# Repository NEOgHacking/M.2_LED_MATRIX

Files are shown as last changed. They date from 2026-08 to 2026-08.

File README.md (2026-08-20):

# M.2 LED Matrix
render

## Description
This is an M.2 compatible LED Matrix board to add an matrix to your desktop PC as a small little display. You can play cool GIFs on this matrix and can control it completely from your PC. This was a speed run done during Kai his ysws speed run. It is made to be as cheep as possible while still being and up to spec M.2 card and uses a 4 layer PCB in the standard 2242 M.2 size. It uses the PCIE protocol to talk to the PC and the PC will be able to send the commands straight to the RP2354 via UART. The RP2354 controls the 11x10 LED matrix and is crammed in on the backside of the PCB.

## Motivation & Idea
I started this project when i was brainstorming in a huddle with allot of people while thinking of ideas for Kai his ysws speedrun. I wanted to create something that would push me a bit and let me learn a bit more about some things but still be doable in 2 days. After some thinking i came up with the beautiful idea to add and LED matrix onto a M.2 card. It would be controlled by a simple microcontroller and it would have a way to interface with the PC it sits in via a protocol over M.2. I settled on the PCIE protocol after a bit of research because it was the one i could get chips for to convert it to UART easily and cheaply, that was one of the other things. This whole project needed to be within budget and that budget isn't big, at $50 it was something to work with. After some researching i found out that the RP2354 was a really cheap microcontroller i could use so i went with that one, also because i know it pretty well.

## Specs
M.2 2242 size
RP2354A microcontroller
CH382L conversion chip
107 LEDs 11x10 matrix
PCIE protocol

## Schematic






## PCB





## BOM

|Reference |Qty|Value |DNP|Exclude from BOM|Exclude from Board|Exclude from Simulation|Exclude from Position Files|Footprint |Datasheet |LCSC |
|---|---|---|---|---|---|---|---|---|---|---|
|C1 |1  |100u | | | | |${EXCLUDE_FROM_POS_FILES}  |Capacitor_Tantalum_SMD:CP_EIA-3528-21_Kemet-B | |C7196 |
|C2,C3 |2  |34p | | | | |${EXCLUDE_FROM_POS_FILES}  |Capacitor_SMD:C_0402_1005Metric | |C70465 |
|C4,C14,C15 |3  |10u | | | | |${EXCLUDE_FROM_POS_FILES}  |Custom:C_Polarized_0805_2012Metric | |C1969735 |
|C5,C6,C7,C9,C10,C11,C12,C13,C16,C26,C28,C29,C30,C31,C32,C33,C34,C36 |18 |100n | | | | |${EXCLUDE_FROM_POS_FILES}  |Capacitor_SMD:C_0402_1005Metric | |C1525 |
|C17,C18,C19,C20 |4  |1u | | | | |${EXCLUDE_FROM_POS_FILES}  |Capacitor_SMD:C_0402_1005Metric | |C29266 |
|C21,C22 |2  |4u7 | | | | |${EXCLUDE_FROM_POS_FILES}  |Custom:C_0402_1005Metric_small_pads | |C23733 |
|C23,C24 |2  |15p | | | | |${EXCLUDE_FROM_POS_FILES}  |Capacitor_SMD:C_0402_1005Metric | |C1548 |
|C25,C27 |2  |4u7 | | | | |${EXCLUDE_FROM_POS_FILES}  |Capacitor_SMD:C_0402_1005Metric | |C23733 |
|D1,D2,D3,D4,D8,D9,D10,D11,D12,D13,D14,D15,D16,D17,D18,D19,D20,D21,D22,D23,D24,D25,D26,D27,D28,D29,D30,D31,D32,D33,D34,D35,D36,D37,D38,D39,D40,D41,D42,D43,D44,D45,D46,D47,D48,D49,D50,D51,D52,D53,D54,D55,D56,D57,D58,D59,D60,D61,D62,D63,D64,D65,D66,D67,D68,D69,D70,D71,D72,D73,D74,D75,D76,D77,D78,D79,D80,D81,D82,D83,D84,D85,D86,D87,D88,D89,D90,D91,D92,D93,D94,D95,D96,D97,D98,D99,D100,D101,D102,D103,D104,D105,D106,D107,D108,D109,D110|107|LED | | | | |${EXCLUDE_FROM_POS_FILES}  |LED_SMD:LED_0603_1608Metric | |C965804  |
|L1 |1  |3u3 | | | | |${EXCLUDE_FROM_POS_FILES}  |Custom:L_pol_2016 | |C42411119|
|R1 |1  |12k | | | | |${EXCLUDE_FROM_POS_FILES}  |Resistor_SMD:R_0402_1005Metric | |C2909316 |
|R2 |1  |0R | | | | |${EXCLUDE_FROM_POS_FILES}  |Resistor_SMD:R_0402_1005Metric | |C106231  |
|R3 |1  |33R | | | | |${EXCLUDE_FROM_POS_FILES}  |Resistor_SMD:R_0402_1005Metric | |C25105 |
|R4,R7 |2  |1k | | | | |${EXCLUDE_FROM_POS_FILES}  |Resistor_SMD:R_0402_1005Metric | |C11702 |
|R5,R6 |2  |27R | | | | |${EXCLUDE_FROM_POS_FILES}  |Resistor_SMD:R_0402_1005Metric | |C2929914 |
|U1 |1  |24C02Cx-x-MNY| | | | |${EXCLUDE_FROM_POS_FILES}  |Package_DFN_QFN:DFN-8-1EP_3x2mm_P0.5mm_EP1.36x1.46mm |https://ww1.microchip.com/downloads/aemDocuments/documents/MPD/ProductDocuments/DataSheets/2-Kbit-5.0V-I2C-Serial-EEPROM-Data-Sheet-DS20001202.pdf|C2061333 |
|U2 |1  |AP2112K-3.3  | | | | |${EXCLUDE_FROM_POS_FILES}  |Package_TO_SOT_SMD:SOT-23-5 |https://www.diodes.com/assets/Datasheets/AP2112.pdf |C51118 |
|U3 |1  |AP2112K-1.8  | | | | |${EXCLUDE_FROM_POS_FILES}  |Package_TO_SOT_SMD:SOT-23-5 |https://www.diodes.com/assets/Datasheets/AP2112.pdf |C176944  |
|U4 |1  |RP23534A | | | | |${EXCLUDE_FROM_POS_FILES}  |Package_DFN_QFN:QFN-60-1EP_7x7mm_P0.4mm_EP3.4x3.4mm_ThermalVias|https://datasheets.raspberrypi.com/rp2350/rp2350-datasheet.pdf |C41378174|
|U5 |1  |CH382L | | | | |${EXCLUDE_FROM_POS_FILES}  |Package_QFP:LQFP-64_7x7mm_P0.4mm | |C2685237 |
|Y1 |1  |22.1184MHz | | | | |${EXCLUDE_FROM_POS_FILES}  |Crystal:Crystal_SMD_3225-4Pin_3.2x2.5mm | |C164060  |
|Y2 |1  |ABM8-272-T3  | | | | |${EXCLUDE_FROM_POS_FILES}  |Crystal:Crystal_SMD_3225-4Pin_3.2x2.5mm | |C20625731|

## Price
PCB 4L 22x42 ENIG    $18.73 excl shipping

LCSC                 $21.25 excl shipping

jlc shipping&tax     $9.95

LCSC shipping&tax    $21.57

Total                $71.50

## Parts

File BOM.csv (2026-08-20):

PCB 4L 22x42 ENIG | $18.73
LCSC shipping&tax | $21.25
jlc shipping&tax | $9.95
LCSC shipping&tax | $21.57
Total | $71.50

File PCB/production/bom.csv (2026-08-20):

Designator | Footprint | Quantity | Value | LCSC Part #
C1 | CP_EIA-3528-21_Kemet-B | 1 | 100u | C7196
C10, C11, C12, C13, C16, C26, C28, C29, C30, C31, C32, C33, C34, C36, C5, C6, C7, C9 | 0402 | 18 | 100n | C1525
C14, C15, C4 | C_Polarized_0805_2012Metric | 3 | 10u | C1969735
C17, C18, C19, C20 | 0402 | 4 | 1u
C2, C3 | 0402 | 2 | C
C21, C22, C25, C27 | 0402 | 4 | 4u7 | C23733
C23, C24 | 0402 | 2 | 15p | C1548
D1, D10, D100, D101, D102, D103, D104, D105, D106, D107, D108, D109, D11, D110, D12, D13, D14, D15, D16, D17, D18, D19, D2, D20, D21, D22, D23, D24, D25, D26, D27, D28, D29, D3, D30, D31, D32, D33, D34, D35, D36, D37, D38, D39, D4, D40, D41, D42, D43, D44, D45, D46, D47, D48, D49, D50, D51, D52, D53, D54, D55, D56, D57, D58, D59, D60, D61, D62, D63, D64, D65, D66, D67, D68, D69, D70, D71, D72, D73, D74, D75, D76, D77, D78, D79, D8, D80, D81, D82, D83, D84, D85, D86, D87, D88, D89, D9, D90, D91, D92, D93, D94, D95, D96, D97, D98, D99 | 0603 | 107 | LED
J1 | M.2_2242-xx-M | 1 | Bus_M.2_Socket_M
L1 | L_pol_2016 | 1 | 3u3 | C42411119
R1 | 0402 | 1 | 12k
R2 | 0402 | 1 | 0R
R3 | 0402 | 1 | 33R | C25105
R4 | 0402 | 1 | 1k | C11702
R5, R6 | 0402 | 2 | 27R | C2929914
R7 | 0402 | 1 | 1k
TP1, TP2, TP3, TP4, TP5, TP6 | TestPoint_Pad_D1.0mm | 6 | TestPoint
U1 | DFN-8-1EP_3x2mm_P0.5mm_EP1.36x1.46mm | 1 | 24C02Cx-x-MNY
U2 | SOT-23-5 | 1 | AP2112K-3.3 | C51118
U3 | SOT-23-5 | 1 | AP2112K-1.8 | C176944
U4 | QFN-60-1EP_7x7mm_P0.4mm_EP3.4x3.4mm_ThermalVias | 1 | RP23534A | C41378174
U5 | LQFP-64_7x7mm_P0.4mm | 1 | CH382L | C2685237
Y1 | Crystal_SMD_3225-4Pin_3.2x2.5mm | 1 | 22.1184MHz | C164060
Y2 | Crystal_SMD_3225-4Pin_3.2x2.5mm | 1 | ABM8-272-T3 | 5A992C

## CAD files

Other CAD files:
Blender/kai_ysws.blend

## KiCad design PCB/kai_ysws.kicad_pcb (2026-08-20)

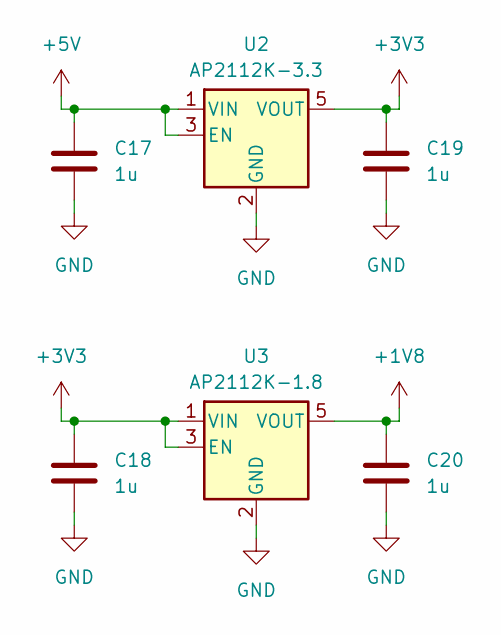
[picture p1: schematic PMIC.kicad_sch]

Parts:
C17, C18, C19, C20: 1u; C_0402_1005Metric; LCSC C29266
U2: AP2112K-3.3; SOT-23-5; LCSC C51118
U3: AP2112K-1.8; SOT-23-5; LCSC C176944

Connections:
+1V8: C20.1, U3.5 (VOUT); also elsewhere on the board
+3V3: C18.1, C19.1, U2.5 (VOUT), U3.1 (VIN), U3.3 (EN); also elsewhere on the board
+5V: C17.1, U2.1 (VIN), U2.3 (EN); also elsewhere on the board
GND: C17.2, C18.2, C19.2, C20.2, U2.2 (GND), U3.2 (GND); also elsewhere on the board

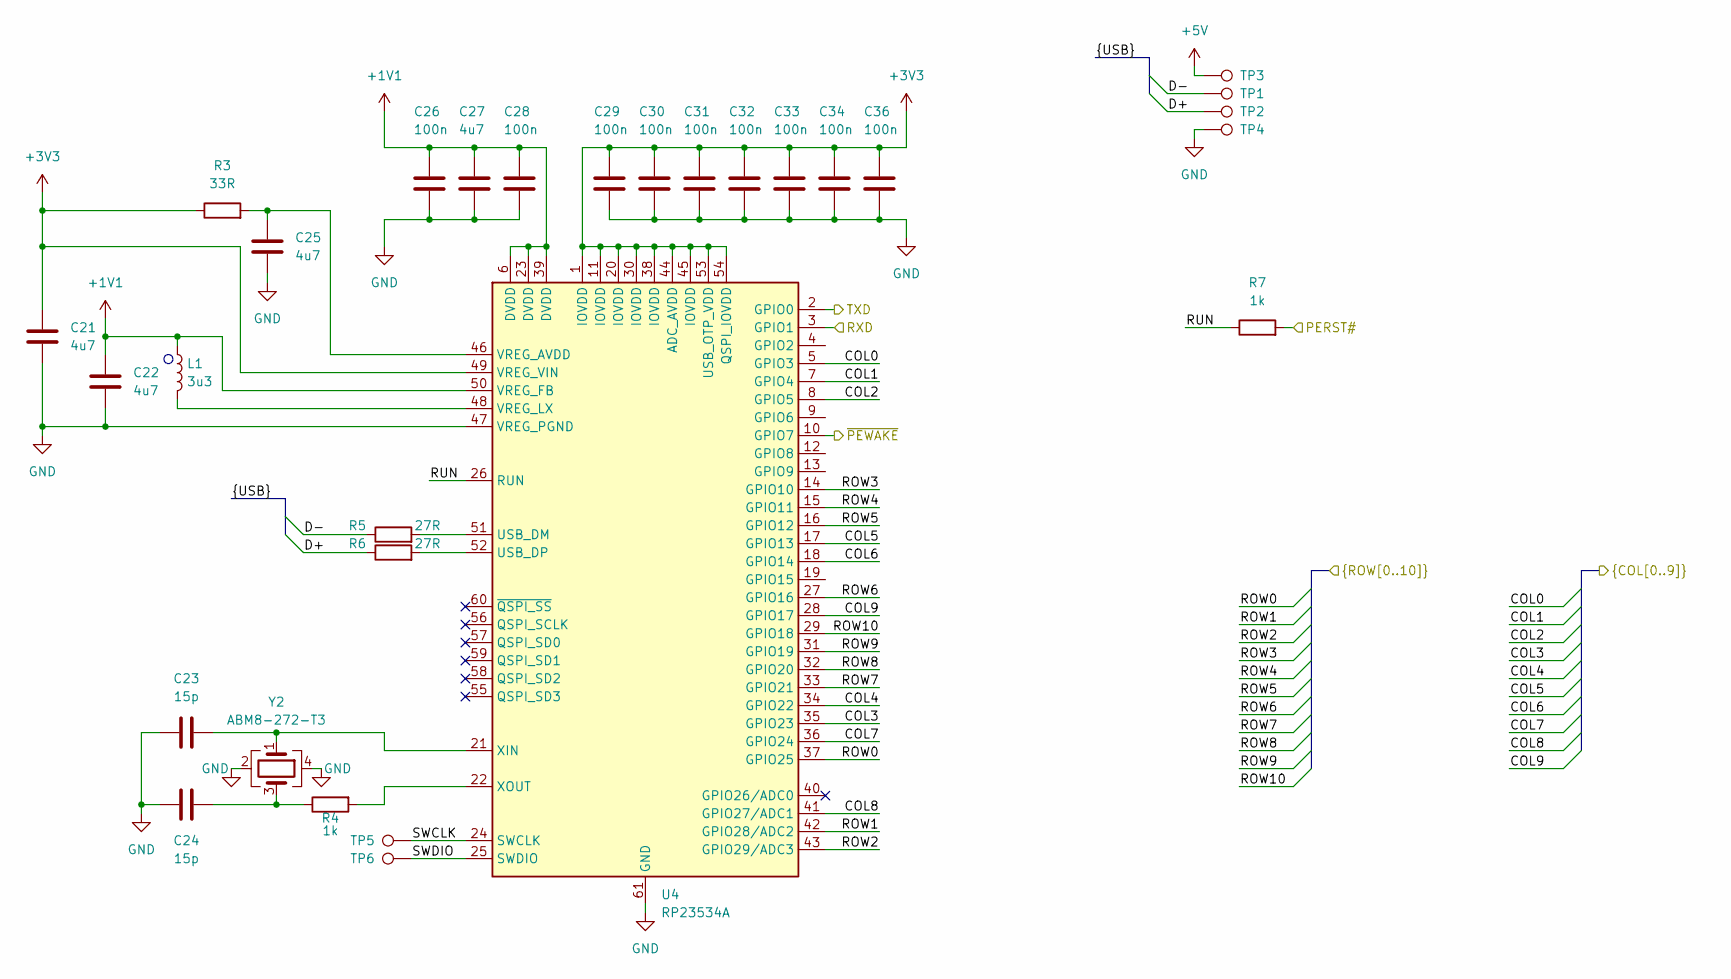
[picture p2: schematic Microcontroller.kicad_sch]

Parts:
C21, C22: 4u7; C_0402_1005Metric_small_pads; LCSC C23733
C23, C24: 15p; C_0402_1005Metric; LCSC C1548
C25, C27: 4u7; C_0402_1005Metric; LCSC C23733
C26, C28, C29, C30, C31, C32, C33, C34, C36: 100n; C_0402_1005Metric; LCSC C1525
L1: 3u3; L_pol_2016; LCSC C42411119
R3: 33R; R_0402_1005Metric; LCSC C25105
R4, R7: 1k; R_0402_1005Metric; LCSC C11702
R5, R6: 27R; R_0402_1005Metric; LCSC C2929914
TP1, TP2, TP3, TP4, TP5, TP6: TestPoint; TestPoint_Pad_D1.0mm
U4: RP23534A; QFN-60-1EP_7x7mm_P0.4mm_EP3.4x3.4mm_ThermalVias; LCSC C41378174
Y2: ABM8-272-T3; Crystal_SMD_3225-4Pin_3.2x2.5mm; LCSC C20625731

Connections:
+1V1: C22.1, C26.1, C27.1, C28.1, L1.1, U4.6 (DVDD), U4.23 (DVDD), U4.39 (DVDD), U4.50 (VREG_FB)
+3V3: C21.1, C29.1, C30.1, C31.1, C32.1, C33.1, C34.1, C36.1, R3.1, U4.1 (IOVDD), U4.11 (IOVDD), U4.20 (IOVDD), U4.30 (IOVDD), U4.38 (IOVDD), U4.44 (ADC_AVDD), U4.45 (IOVDD), U4.49 (VREG_VIN), U4.53 (USB_OTP_VDD), U4.54 (QSPI_IOVDD); also elsewhere on the board
+5V: TP3.1 (1_1); also elsewhere on the board
/M.2 slot/PERST#: R7.2; also elsewhere on the board
/M.2 slot/~PEWAKE: U4.10 (GPIO7); also elsewhere on the board
/M.2 to UART/RXD: U4.2 (GPIO0); also elsewhere on the board
/M.2 to UART/TXD: U4.3 (GPIO1); also elsewhere on the board
/Matrix/COL0: U4.5 (GPIO3); also elsewhere on the board
/Matrix/COL1: U4.7 (GPIO4); also elsewhere on the board
/Matrix/COL2: U4.8 (GPIO5); also elsewhere on the board
/Matrix/COL3: U4.35 (GPIO23); also elsewhere on the board
/Matrix/COL4: U4.34 (GPIO22); also elsewhere on the board
/Matrix/COL5: U4.17 (GPIO13); also elsewhere on the board
/Matrix/COL6: U4.18 (GPIO14); also elsewhere on the board
/Matrix/COL7: U4.36 (GPIO24); also elsewhere on the board
/Matrix/COL8: U4.41 (GPIO27/ADC1); also elsewhere on the board
/Matrix/COL9: U4.28 (GPIO17); also elsewhere on the board
/Matrix/ROW0: U4.37 (GPIO25); also elsewhere on the board
/Matrix/ROW1: U4.42 (GPIO28/ADC2); also elsewhere on the board
/Matrix/ROW2: U4.43 (GPIO29/ADC3); also elsewhere on the board
/Matrix/ROW3: U4.14 (GPIO10); also elsewhere on the board
/Matrix/ROW4: U4.15 (GPIO11); also elsewhere on the board
/Matrix/ROW5: U4.16 (GPIO12); also elsewhere on the board
/Matrix/ROW6: U4.27 (GPIO16); also elsewhere on the board
/Matrix/ROW7: U4.33 (GPIO21); also elsewhere on the board
/Matrix/ROW8: U4.32 (GPIO20); also elsewhere on the board
/Matrix/ROW9: U4.31 (GPIO19); also elsewhere on the board
/Matrix/ROW10: U4.29 (GPIO18); also elsewhere on the board
/Microcontroller/D+: R6.1, TP2.1 (1_1)
/Microcontroller/D-: R5.1, TP1.1 (1_1)
/Microcontroller/RUN: R7.1, U4.26 (RUN)
/Microcontroller/SWCLK: TP5.1 (1_1), U4.24 (SWCLK)
/Microcontroller/SWDIO: TP6.1 (1_1), U4.25 (SWDIO)
GND: C21.2, C22.2, C23.1, C24.1, C25.2, C26.2, C27.2, C28.2, C29.2, C30.2, C31.2, C32.2, C33.2, C34.2, C36.2, TP4.1 (1_1), U4.47 (VREG_PGND), U4.61 (GND), Y2.2 (G), Y2.4 (G); also elsewhere on the board
unnamed: C24.2, R4.1, Y2.3
unnamed: R5.2, U4.51 (USB_DM)
unnamed: R6.2, U4.52 (USB_DP)
unnamed: C25.1, R3.2, U4.46 (VREG_AVDD)
unnamed: L1.2, U4.48 (VREG_LX)
unnamed: C23.2, U4.21 (XIN), Y2.1
unnamed: R4.2, U4.22 (XOUT)

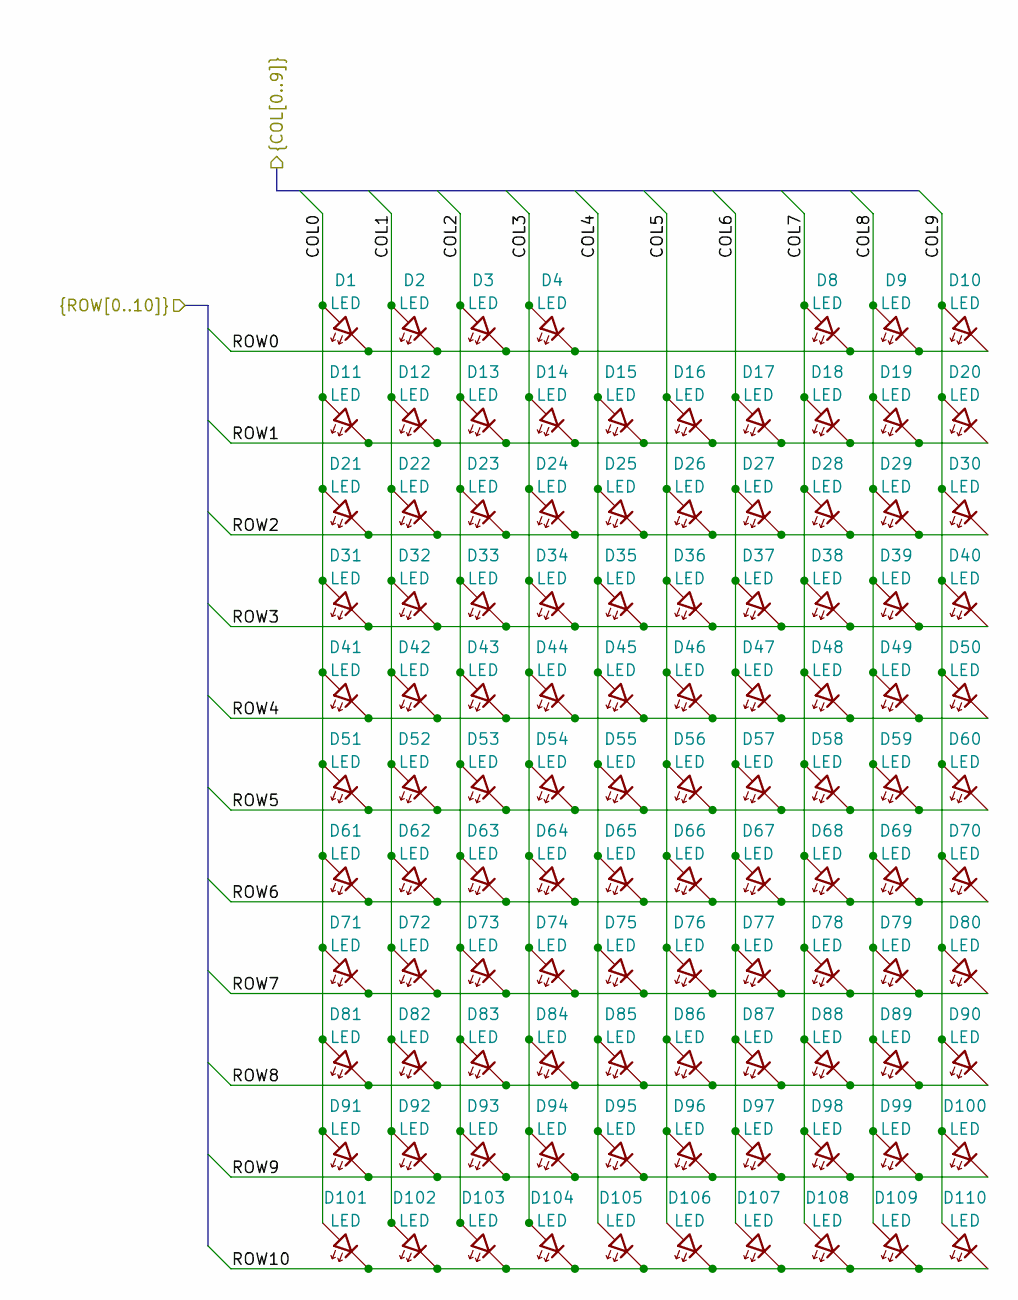
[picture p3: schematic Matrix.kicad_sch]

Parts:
D1, D2, D3, D4, D8, D9, D10, D11, D12, D13, D14, D15, D16, D17, D18, D19, D20, D21, D22, D23, D24, D25, D26, D27, D28, D29, D30, D31, D32, D33, D34, D35, D36, D37, D38, D39, D40, D41, D42, D43, D44, D45, D46, D47, D48, D49, D50, D51, D52, D53, D54, D55, D56, D57, D58, D59, D60, D61, D62, D63, D64, D65, D66, D67, D68, D69, D70, D71, D72, D73, D74, D75, D76, D77, D78, D79, D80, D81, D82, D83, D84, D85, D86, D87, D88, D89, D90, D91, D92, D93, D94, D95, D96, D97, D98, D99, D100, D101, D102, D103, D104, D105, D106, D107, D108, D109, D110: LED; LED_0603_1608Metric; LCSC C965804

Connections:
/Matrix/COL0: D1.2 (A), D11.2 (A), D21.2 (A), D31.2 (A), D41.2 (A), D51.2 (A), D61.2 (A), D71.2 (A), D81.2 (A), D91.2 (A), D101.2 (A); also elsewhere on the board
/Matrix/COL1: D2.2 (A), D12.2 (A), D22.2 (A), D32.2 (A), D42.2 (A), D52.2 (A), D62.2 (A), D72.2 (A), D82.2 (A), D92.2 (A), D102.2 (A); also elsewhere on the board
/Matrix/COL2: D3.2 (A), D13.2 (A), D23.2 (A), D33.2 (A), D43.2 (A), D53.2 (A), D63.2 (A), D73.2 (A), D83.2 (A), D93.2 (A), D103.2 (A); also elsewhere on the board
/Matrix/COL3: D4.2 (A), D14.2 (A), D24.2 (A), D34.2 (A), D44.2 (A), D54.2 (A), D64.2 (A), D74.2 (A), D84.2 (A), D94.2 (A), D104.2 (A); also elsewhere on the board
/Matrix/COL4: D15.2 (A), D25.2 (A), D35.2 (A), D45.2 (A), D55.2 (A), D65.2 (A), D75.2 (A), D85.2 (A), D95.2 (A), D105.2 (A); also elsewhere on the board
/Matrix/COL5: D16.2 (A), D26.2 (A), D36.2 (A), D46.2 (A), D56.2 (A), D66.2 (A), D76.2 (A), D86.2 (A), D96.2 (A), D106.2 (A); also elsewhere on the board
/Matrix/COL6: D17.2 (A), D27.2 (A), D37.2 (A), D47.2 (A), D57.2 (A), D67.2 (A), D77.2 (A), D87.2 (A), D97.2 (A), D107.2 (A); also elsewhere on the board
/Matrix/COL7: D8.2 (A), D18.2 (A), D28.2 (A), D38.2 (A), D48.2 (A), D58.2 (A), D68.2 (A), D78.2 (A), D88.2 (A), D98.2 (A), D108.2 (A); also elsewhere on the board
/Matrix/COL8: D9.2 (A), D19.2 (A), D29.2 (A), D39.2 (A), D49.2 (A), D59.2 (A), D69.2 (A), D79.2 (A), D89.2 (A), D99.2 (A), D109.2 (A); also elsewhere on the board
/Matrix/COL9: D10.2 (A), D20.2 (A), D30.2 (A), D40.2 (A), D50.2 (A), D60.2 (A), D70.2 (A), D80.2 (A), D90.2 (A), D100.2 (A), D110.2 (A); also elsewhere on the board
/Matrix/ROW0: D1.1 (K), D2.1 (K), D3.1 (K), D4.1 (K), D8.1 (K), D9.1 (K), D10.1 (K); also elsewhere on the board
/Matrix/ROW1: D11.1 (K), D12.1 (K), D13.1 (K), D14.1 (K), D15.1 (K), D16.1 (K), D17.1 (K), D18.1 (K), D19.1 (K), D20.1 (K); also elsewhere on the board
/Matrix/ROW2: D21.1 (K), D22.1 (K), D23.1 (K), D24.1 (K), D25.1 (K), D26.1 (K), D27.1 (K), D28.1 (K), D29.1 (K), D30.1 (K); also elsewhere on the board
/Matrix/ROW3: D31.1 (K), D32.1 (K), D33.1 (K), D34.1 (K), D35.1 (K), D36.1 (K), D37.1 (K), D38.1 (K), D39.1 (K), D40.1 (K); also elsewhere on the board
/Matrix/ROW4: D41.1 (K), D42.1 (K), D43.1 (K), D44.1 (K), D45.1 (K), D46.1 (K), D47.1 (K), D48.1 (K), D49.1 (K), D50.1 (K); also elsewhere on the board
/Matrix/ROW5: D51.1 (K), D52.1 (K), D53.1 (K), D54.1 (K), D55.1 (K), D56.1 (K), D57.1 (K), D58.1 (K), D59.1 (K), D60.1 (K); also elsewhere on the board
/Matrix/ROW6: D61.1 (K), D62.1 (K), D63.1 (K), D64.1 (K), D65.1 (K), D66.1 (K), D67.1 (K), D68.1 (K), D69.1 (K), D70.1 (K); also elsewhere on the board
/Matrix/ROW7: D71.1 (K), D72.1 (K), D73.1 (K), D74.1 (K), D75.1 (K), D76.1 (K), D77.1 (K), D78.1 (K), D79.1 (K), D80.1 (K); also elsewhere on the board
/Matrix/ROW8: D81.1 (K), D82.1 (K), D83.1 (K), D84.1 (K), D85.1 (K), D86.1 (K), D87.1 (K), D88.1 (K), D89.1 (K), D90.1 (K); also elsewhere on the board
/Matrix/ROW9: D91.1 (K), D92.1 (K), D93.1 (K), D94.1 (K), D95.1 (K), D96.1 (K), D97.1 (K), D98.1 (K), D99.1 (K), D100.1 (K); also elsewhere on the board
/Matrix/ROW10: D101.1 (K), D102.1 (K), D103.1 (K), D104.1 (K), D105.1 (K), D106.1 (K), D107.1 (K), D108.1 (K), D109.1 (K), D110.1 (K); also elsewhere on the board

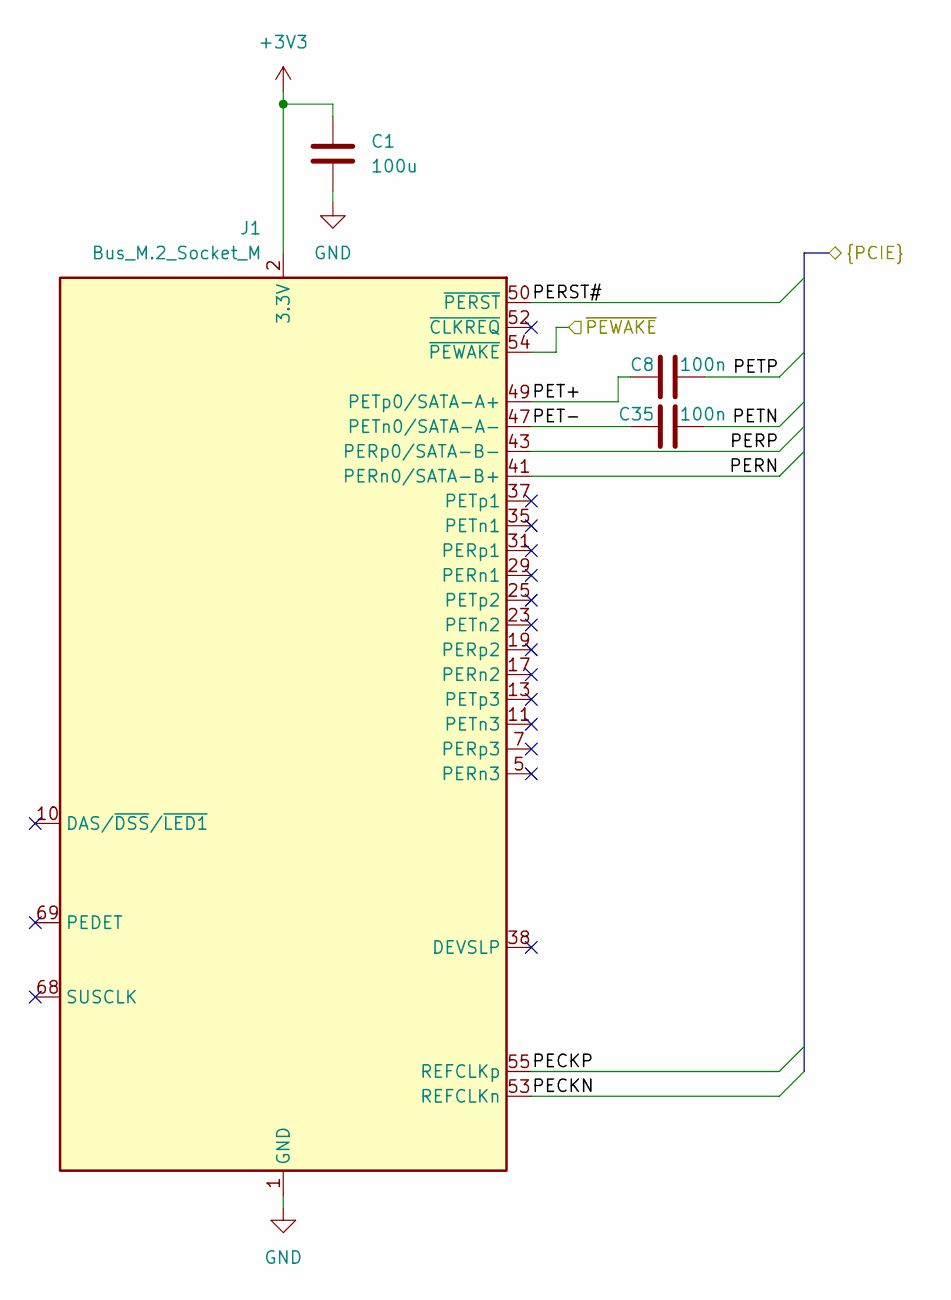
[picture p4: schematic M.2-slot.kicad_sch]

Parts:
C1: 100u; CP_EIA-3528-21_Kemet-B; LCSC C7196
C8, C35: 100n; C_0402_1005Metric; LCSC C1525
J1: Bus_M.2_Socket_M; M.2_2242-xx-M

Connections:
+3V3: C1.1, J1.2 (3.3V), J1.4 (3.3V), J1.12 (3.3V), J1.14 (3.3V), J1.16 (3.3V), J1.18 (3.3V), J1.70 (3.3V), J1.72 (3.3V), J1.74 (3.3V); also elsewhere on the board
/M.2 slot/PECKN: J1.53 (REFCLKn); also elsewhere on the board
/M.2 slot/PECKP: J1.55 (REFCLKp); also elsewhere on the board
/M.2 slot/PERN: J1.41 (PERn0/SATA-B+); also elsewhere on the board
/M.2 slot/PERP: J1.43 (PERp0/SATA-B-); also elsewhere on the board
/M.2 slot/PERST#: J1.50 (~PERST); also elsewhere on the board
/M.2 slot/PET+: C8.1, J1.49 (PETp0/SATA-A+)
/M.2 slot/PET-: C35.1, J1.47 (PETn0/SATA-A-)
/M.2 slot/PETN: C35.2; also elsewhere on the board
/M.2 slot/PETP: C8.2; also elsewhere on the board
/M.2 slot/~PEWAKE: J1.54 (~PEWAKE); also elsewhere on the board
GND: C1.2, J1.1 (GND), J1.3 (GND), J1.9 (GND), J1.15 (GND), J1.21 (GND), J1.27 (GND), J1.33 (GND), J1.39 (GND), J1.45 (GND), J1.51 (GND), J1.57 (GND), J1.71 (GND), J1.73 (GND), J1.75 (GND); also elsewhere on the board

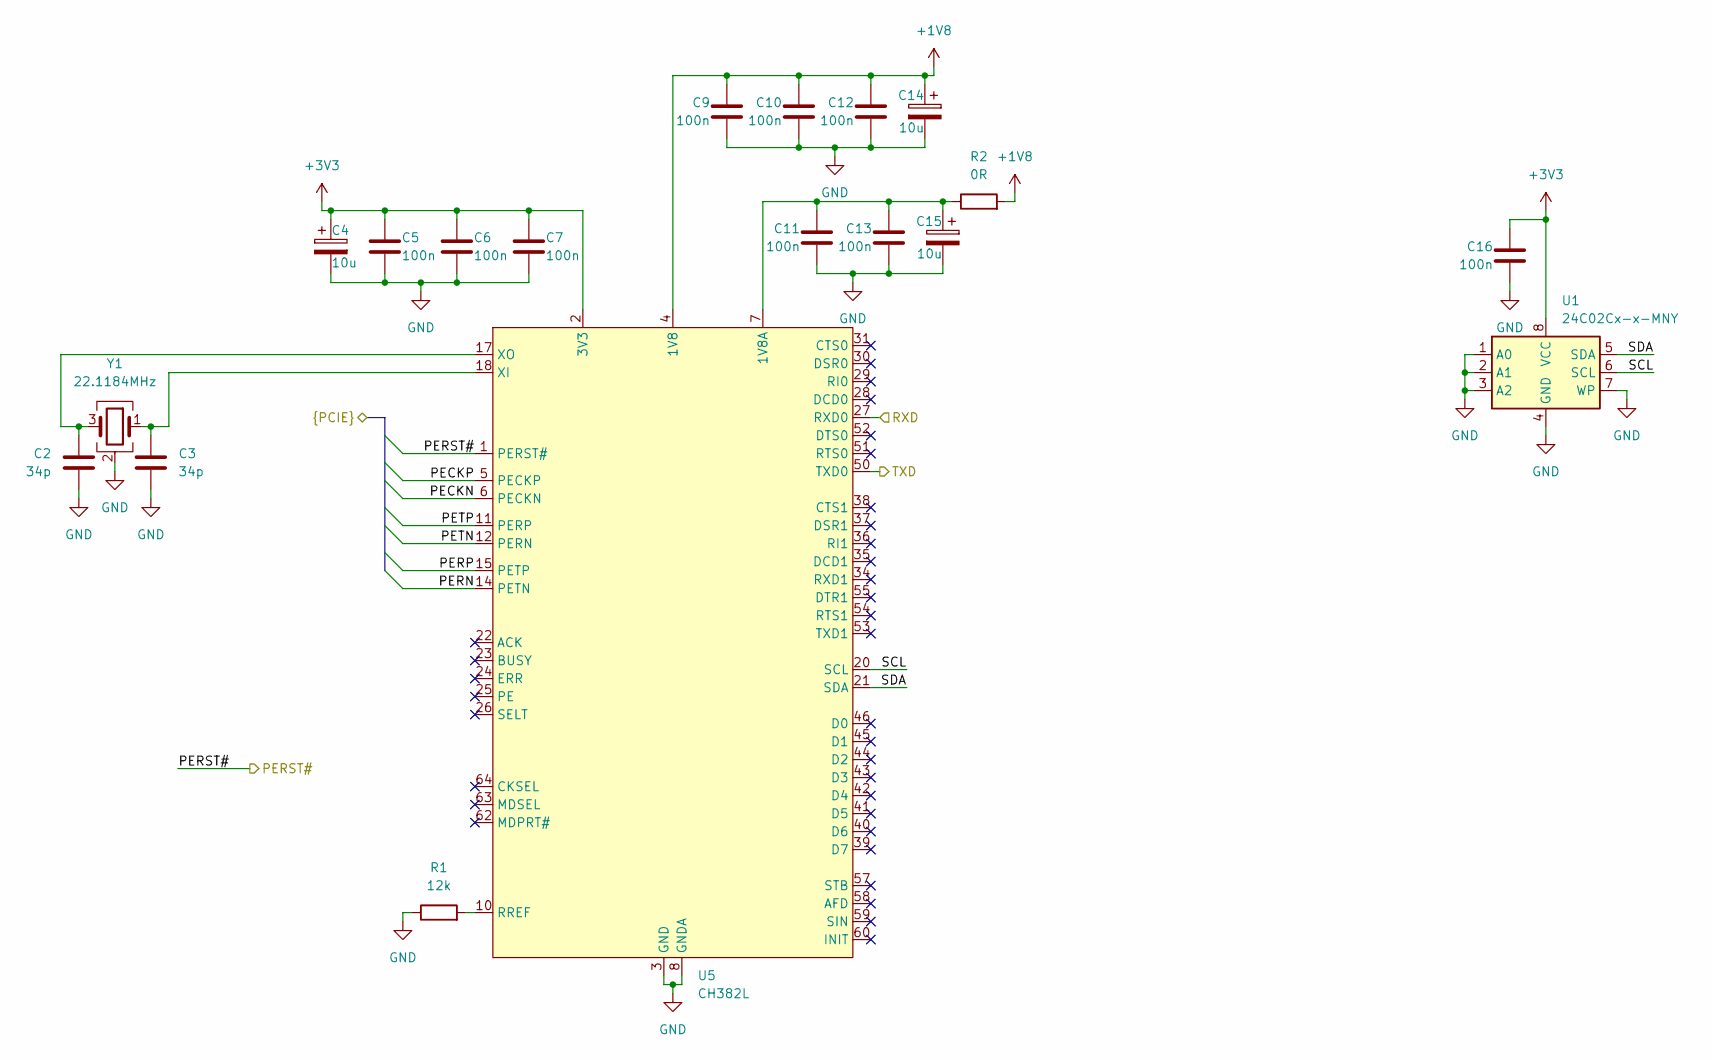
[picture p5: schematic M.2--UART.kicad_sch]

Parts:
C2, C3: 34p; C_0402_1005Metric; LCSC C70465
C4, C14, C15: 10u; C_Polarized_0805_2012Metric; LCSC C1969735
C5, C6, C7, C9, C10, C11, C12, C13, C16: 100n; C_0402_1005Metric; LCSC C1525
R1: 12k; R_0402_1005Metric; LCSC C2909316
R2: 0R; R_0402_1005Metric; LCSC C106231
U1: 24C02Cx-x-MNY; DFN-8-1EP_3x2mm_P0.5mm_EP1.36x1.46mm; LCSC C2061333
U5: CH382L; LQFP-64_7x7mm_P0.4mm; LCSC C2685237
Y1: 22.1184MHz; Crystal_SMD_3225-4Pin_3.2x2.5mm; LCSC C164060

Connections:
1V8A: C11.1, C13.1, C15.1, R2.1, U5.7 (1V8A), U5.13 (1V8A)
+1V8: C9.1, C10.1, C12.1, C14.1, R2.2, U5.4 (1V8), U5.32 (1V8), U5.47 (1V8); also elsewhere on the board
+3V3: C4.1, C5.1, C6.1, C7.1, C16.1, U1.8 (VCC), U5.2 (3V3), U5.19 (3V3), U5.49 (3V3); also elsewhere on the board
/M.2 slot/PECKN: U5.6 (PECKN); also elsewhere on the board
/M.2 slot/PECKP: U5.5 (PECKP); also elsewhere on the board
/M.2 slot/PERN: U5.14 (PETN); also elsewhere on the board
/M.2 slot/PERP: U5.15 (PETP); also elsewhere on the board
/M.2 slot/PERST#: U5.1 (PERST#); also elsewhere on the board
/M.2 slot/PETN: U5.12 (PERN); also elsewhere on the board
/M.2 slot/PETP: U5.11 (PERP); also elsewhere on the board
/M.2 to UART/RXD: U5.27 (RXD0); also elsewhere on the board
/M.2 to UART/SCL: U1.6 (SCL), U5.20 (SCL)
/M.2 to UART/SDA: U1.5 (SDA), U5.21 (SDA)
/M.2 to UART/TXD: U5.50 (TXD0); also elsewhere on the board
GND: C2.2, C3.2, C4.2, C5.2, C6.2, C7.2, C9.2, C10.2, C11.2, C12.2, C13.2, C14.2, C15.2, C16.2, R1.1, U1.1 (A0), U1.2 (A1), U1.3 (A2), U1.4 (GND), U1.7 (WP), U1.9 (GND), U5.3 (GND), U5.8 (GNDA), U5.9 (GNDA), U5.16 (GND), U5.33 (GND), U5.48 (GND), U5.56 (GND), U5.61 (GND), Y1.2 (G), Y1.4 (G); also elsewhere on the board
unnamed: R1.2, U5.10 (RREF)
unnamed: C3.1, U5.18 (XI), Y1.1
unnamed: C2.1, U5.17 (XO), Y1.3

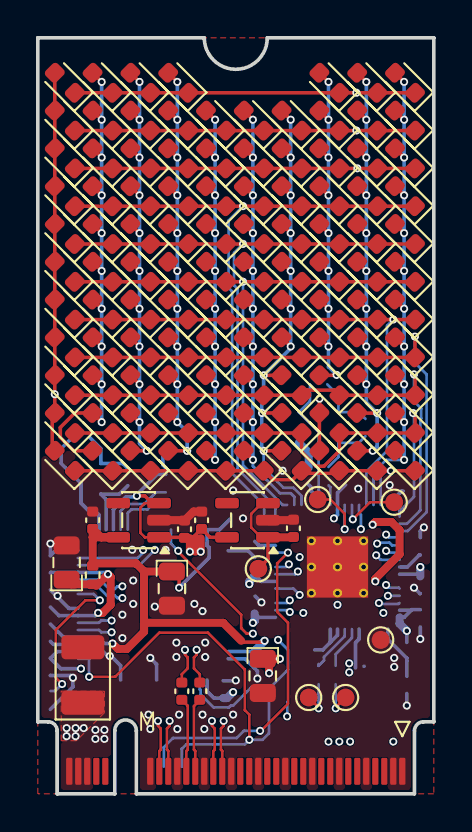
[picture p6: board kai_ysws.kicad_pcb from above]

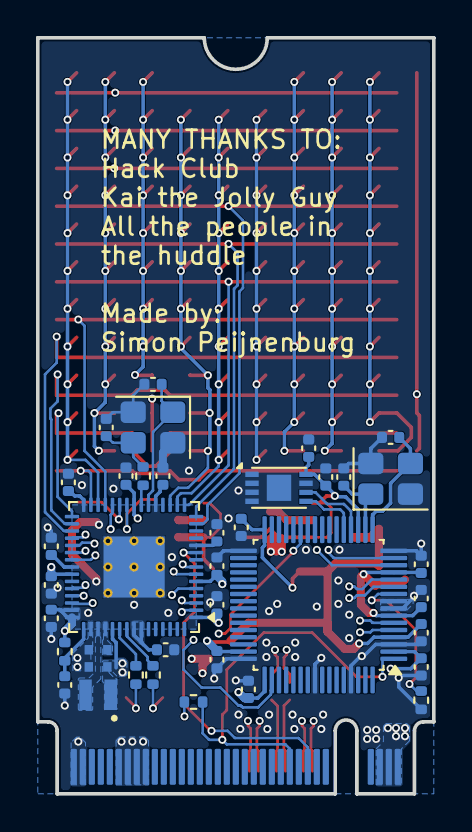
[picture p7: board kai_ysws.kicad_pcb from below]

Board: 4 copper layers, 22.0 x 42.0 mm, 165 parts (38 on the bottom side), 56 nets.

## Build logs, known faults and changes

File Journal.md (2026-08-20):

# Day 1 3h

This was a late night when i heard that my friend was doing a ysws speed run so of course i had to participate. At first there was a big brainstorming session when i came to the conclusion i would make an M.2 LED matrix. This was what i wanted to make but i had to make it as cheap as possible, so at first i looked at the PCB, the biggest size i could get that would be under the 50x50 price point of 
jlcpcb was the 2242, everything above that was too long, but i wanted it as big as possible. Then i dove a bit into M.2 socket types and found out i needed to get a M type socked because its the most common on PC and its used widely. Then i finally had chosen what size M.2 i wanted but still needed to look for the IC's necessary to get this thing to work, i wanted to have it be able to communicate with 
the PC to be able to switch grapics or GIFs. This will be done over PCIE because on an M socket there is only PCIE and SATA, and SATA is only storage so i would need to go for PCIE.



After having choosen that i went looking on LCSC for an PCIE to USB or UART converter to be able to talk to the RP2354. After a bit of a search i settled on this CH382L chip that has dual UART outputs of which i would only need one.



Then i choose the RP2354A microcontroller because of its price, size, and my knowledge of it.



Then i knew which IC's i would want but was still unsure of what size of LED matrix i would want, but i would decide that when i have the rest build so i could see how much space i would have left.

# Day 2 8h

So i started by laying out a general schematic

Screenshot From 2026-08-19 01-04-58

Then i started on creating my own CH382L footprint because there didn't exist one yet, this was a long time to get all the pins correct and the right name. For this i devoured the whole datasheet from the inside out and learned the chip far enough that i got a good understanding of its workings.

Screenshot From 2026-08-19 01-14-08

Screenshot From 2026-08-19 01-17-24

Screenshot From 2026-08-19 01-21-50

Screenshot From 2026-08-19 01-35-25

Then when this was done i started on the decoupling of the IC as per the datasheet. But with almost all IC's its just 100nf per pin and 1-2.2 uf bulk cap so this was pretty easy.

Screenshot From 2026-08-19 01-45-32

Then i schematic of the M.2 card, this was kinda difficult because there can be 2 protocols over the same pins and you need to select which one you want and need to select the right pins for that protocol and then also decide what to do with the other strange pins the M.2 standard has. But i made a bus so it would be easier to transfer the right stuff to the IC.

Screenshot From 2026-08-19 02-14-15

After this i made the whole schematic of the PCIE to UART converter with all the connections and stuff that was needed

Screenshot From 2026-08-19 17-02-21

After this i started on the RP2354 schematic, at this time it has become almost automatic with how many times i have done this. I used the internal flash because it was cheaper and easier to implement apart from that i went with the A version for space reasons.

Screenshot From 2026-08-19 17-02-06

Now it was time to get stared on the layout, at first i assigned all the components correctly with the right sizes for the right components so that i could go to the layout stage.



At first i started on the PCIE to UART converter and did all the decoupling and added the crystal and all the rest that was necessary for the ic.

Screenshot From 2026-08-19 17-45-56

# Day 3 8h

So woke up bright and early today at 11am to get started with the layout, the one and only dreaded layout. I was kinda locked in really really hard today so also forgot to take as much screenshots as i did the previous times. So i will try to explain and show as good as possible what i did.
At first this day i started with the RP layout, as per the not findable guidelines that RP has.



After that i did the high speed PCIE routing for the PCIE to UART converter. This was done using the impedance calculator of JLC to ensure the right impedance for the high speed traces.
I used the inner layer, because on the top and bottom there where components scattered around so it would have been difficult to get them out of the way for the high speed traces so i went for an inner layer.



Then i started on the layout for the LDO's that are used in the PCB because i needed to have as much space as possible for the LED matrix i am gonna add.



To be honest it has been the most shitty and most complex PCB i have ever made in terms of power traces for power delivery because of the compactness of this PCB



After the power stuff was done it was time to get the LED matrix made, i did some test fits and after i did all those test fits i decided on a 11x10 matrix. I made the matrix in the schematic and decided on Green 0603 LEDs for the matrix.




After these where made, i slowly made the pinout of the rp based on how i could route stuff.





This is how the main schematic page turned out.



And here is how the PCB turned out after all the routing.





Then i put it in blender and made this render.

render

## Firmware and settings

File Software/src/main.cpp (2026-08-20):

#include <Arduino.h>

int COLUMNS[10] = {3, 4, 5, 23, 22, 13, 14, 24, 27, 17};
int ROWS[11] = {25, 28, 29, 10, 11, 12, 16, 21, 20, 19, 18};



void setup() {
  Serial.begin(115200);

  for(int COL : COLUMNS) {
    pinMode(COL, OUTPUT);
  }
  for(int ROW : ROWS) {
    pinMode(ROW, OUTPUT);
  }
}

void loop() {
  for (int COL : COLUMNS) {
    digitalWrite(COL, LOW);
    for (int ROW :ROWS) {
      for(int i; i <= 1000; i++) {
        digitalWrite(ROW, HIGH);
        delay(1);
        digitalWrite(ROW, LOW);
        delay(1);
      }
    }
  }
}

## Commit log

2026-08-20 Upload everything
    [M.2--UART.kicad_sch, M.2-slot.kicad_sch, Matrix.kicad_sch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]
2026-08-20 fixed bom
    [Matrix.kicad_sch, kai_ysws.csv]
2026-08-20 Revise README with project details and specifications
    Updated the README to provide detailed project information including description, motivation, specifications, schematic, PCB images, BOM, and pricing.
2026-08-20 Revise pricing information in README
    Updated pricing details for PCB and components.
2026-08-20 Revise pricing details in README
    Updated price information for PCB and shipping costs.
2026-08-20 fixed Bom again and small pcb things
    [bom.csv, designators.csv, kai_ysws.csv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]
2026-08-20 Added BOM
    [BOM.csv]
2026-08-20 Document progress on M.2 LED matrix project
    Detailed the progress over three days of designing an M.2 LED matrix, including schematic creation, component selection, and PCB layout.
2026-08-20 Fix image filename case in Journal.md
2026-08-20 Added silkscreen
    [M.2-slot.kicad_sch, kai_ysws.kicad_pcb]
2026-08-20 Added software
    [Microcontroller.kicad_sch]
